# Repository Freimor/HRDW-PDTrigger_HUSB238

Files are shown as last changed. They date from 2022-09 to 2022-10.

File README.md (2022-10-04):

## PD Trigger module on Hynetek HUSB238 chip
This is a rework of [Hynetek HUSB238 evaluation board](https://www.hynetek.com/uploadfiles/site/219/files/23877051-9b40-4ae7-b10f-7e32536c2083.pdf) with minor changes. In general, i just added a fuse and reroute schematic for using available components from AliExpress.

The project is completed in Q4 2022.

 

## Parameters for PCB order (JLCPCB compatible)
2 layer board

0.8mm thickness

0.25mm min hole size

Castellated holes

## BOM list
| №  | Designator  | Qty | Description | Manufacturer  | Name | Package  | Link |
| -- | --- | --- | --- | --- | --- | --- | ---- |
| 1  | C1, C2 | 2 | 330pf MLCC | | | 0402 | |
| 2  | C3 | 1 | 1uF MLCC | | | 0402 | |
| 3  | R1 | 1 | 100kΩ smd resistor | | | 0402 | |
| 4  | R2 | 1 | 10Ω smd resistor | | | 0402 | |
| 5  | R3 | 1 | 30kΩ smd resistor  | | | 0402 | |
| 6  | R4, R5 | 2 | Choose a value based on the output characteristics  | | | 0805 | |
| 7  | R6 | 1 | 1MΩ smd resistor | | | 0402 | |
| 8  | D1,D2,D3,D4 | 4 | TVS diod | Littelfuse | PGB1010603 | 0603 | [AliExpress](https://aliexpress.ru/item/32895822186.html) |
| 9  | F1 | 1 | SMD Fuse | | | 1808 | [AliExpress](https://aliexpress.ru/item/33048094198.html) |
| 10 | J5 | 1 | USB Type-C 16pin | GCT | USB4505-03-0-A | | [AliExpress](https://aliexpress.ru/item/33013020868.html) |
| 11 | Q1 | 1 | P-MOSFET 30V | Alpha & Omega | AON7403 | DFN3x3EP | [AliExpress](https://aliexpress.ru/item/1005003805312191.html) |
| 12 | U1 | 1 | PD controller | Hynetek | HUSB238 | DFN-10 | [AliExpress](https://aliexpress.ru/item/1005002906568952.html) |

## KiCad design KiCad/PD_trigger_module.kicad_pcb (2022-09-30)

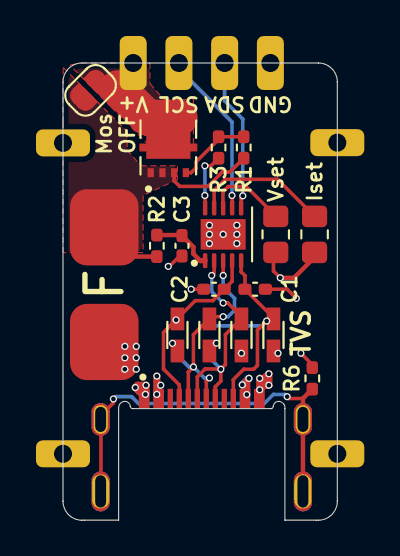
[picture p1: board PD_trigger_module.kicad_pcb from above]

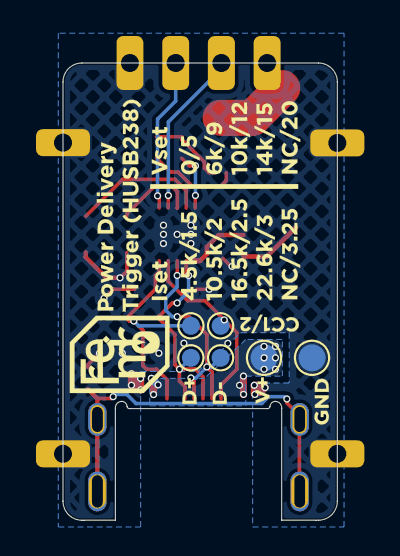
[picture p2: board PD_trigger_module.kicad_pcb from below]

Board: 2 copper layers, 15.2 x 25.4 mm, 33 parts (7 on the bottom side), 16 nets.

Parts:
C1, C2: 330pF; C_0402_1005Metric_Pad0.74x0.62mm_HandSolder
C3: 1uF; C_0402_1005Metric_Pad0.74x0.62mm_HandSolder
CC1, CC1/2-: TestPoint_Pad_D1.0mm
D1, D2, D3, D4: D_TVS; ESD_PGB1010603MR
D+: TestPoint_Pad_D1.0mm
D-: TestPoint_Pad_D1.0mm
F1: Fuse_Small; FuseHolder_1808
GND: Conn_01x01_Female; Castellated_hole_2.54
GND#2: TestPoint_Pad_D1.5mm
Iset: Iset; R_0805_2012Metric_Pad1.20x1.40mm_HandSolder
J2, J2#2, J2#3, J2#4: Conn_01x01_Female; Castellated_hole_2.54
J5: USB_C_Receptacle_USB2.0; TYPE_C_GCT_USB4505-03-0-A
JP1: SolderJumper_2_Open; SolderJumper-2_P1.3mm_Open_RoundedPad1.0x1.5mm
Q1: AON7403
R1: 100k; R_0402_1005Metric_Pad0.72x0.64mm_HandSolder
R2: 10; R_0402_1005Metric_Pad0.72x0.64mm_HandSolder
R3: 30k; R_0402_1005Metric_Pad0.72x0.64mm_HandSolder
R6: 1M; R_0402_1005Metric_Pad0.72x0.64mm_HandSolder
Ref**: Val**; drawing
SCL: Conn_01x01_Female; Castellated_hole_2.54
SDA: Conn_01x01_Female; Castellated_hole_2.54
U1: HUSB238; HUSB238_Hynetek
V+: Conn_01x01_Female; Castellated_hole_2.54
V+#2: TestPoint_Pad_D1.5mm
Vset: Vset; R_0805_2012Metric_Pad1.20x1.40mm_HandSolder

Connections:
unnamed: C1.1, CC1/2-.1, D3.2 (A2), J5.B5 (CC2), U1.5 (CC2)
unnamed: C2.1, CC1.1, D4.2 (A2), J5.A5 (CC1), U1.4 (CC1)
unnamed: C3.1, R2.2, U1.1 (VIN)
unnamed: D1.2 (A2), D+.1, J5.A6 (D+), J5.B6 (D+), U1.2 (D+)
unnamed: D2.2 (A2), D-.1, J5.A7 (D-), J5.B7 (D-), U1.3 (D-)
unnamed: F1.1, J5.A4 (VBUS), J5.A9 (VBUS), J5.B4 (VBUS), J5.B9 (VBUS), V+#2.1
unnamed: F1.2, JP1.1 (A), Q1.1 (S), Q1.2 (S), Q1.3 (S), R1.1, R2.1
unnamed: J5.S1 (SHIELD), R6.1
unnamed: Q1.4 (G), R1.2, R3.1
unnamed: R3.2, U1.10 (GATE)
unnamed: U1.8 (Vset), Vset.1
unnamed: Iset.1, U1.9 (Iset)
SCL: SCL.1, U1.7 (SCL)
SDA: SDA.1, U1.6 (SDA)
Vdd: C1.2, C2.2, C3.2, D1.1 (A1), D2.1 (A1), D3.1 (A1), D4.1 (A1), GND.1, GND#2.1, Iset.2, J2.1, J2#2.1, J2#3.1, J2#4.1, J5.A1 (GND), J5.A12 (GND), J5.B1 (GND), J5.B12 (GND), R6.2, U1.11 (GND), Vset.2
Vss: JP1.2 (B), Q1.5 (D), Q1.6 (D), Q1.7 (D), Q1.8 (D), V+.1

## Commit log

2022-09-27 Add KiCad files
    [PD_trigger_module.kicad_pcb, PD_trigger_module.kicad_sch]
2022-09-27 Add BOM list to README
2022-09-28 Some minor corrections
    [PD_trigger_module.kicad_pcb, PD_trigger_module.kicad_sch]
2022-09-30 Design update
    [PD_trigger_module.kicad_pcb]
